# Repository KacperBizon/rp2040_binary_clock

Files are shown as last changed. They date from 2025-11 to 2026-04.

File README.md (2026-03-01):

# rp2040 binary clock
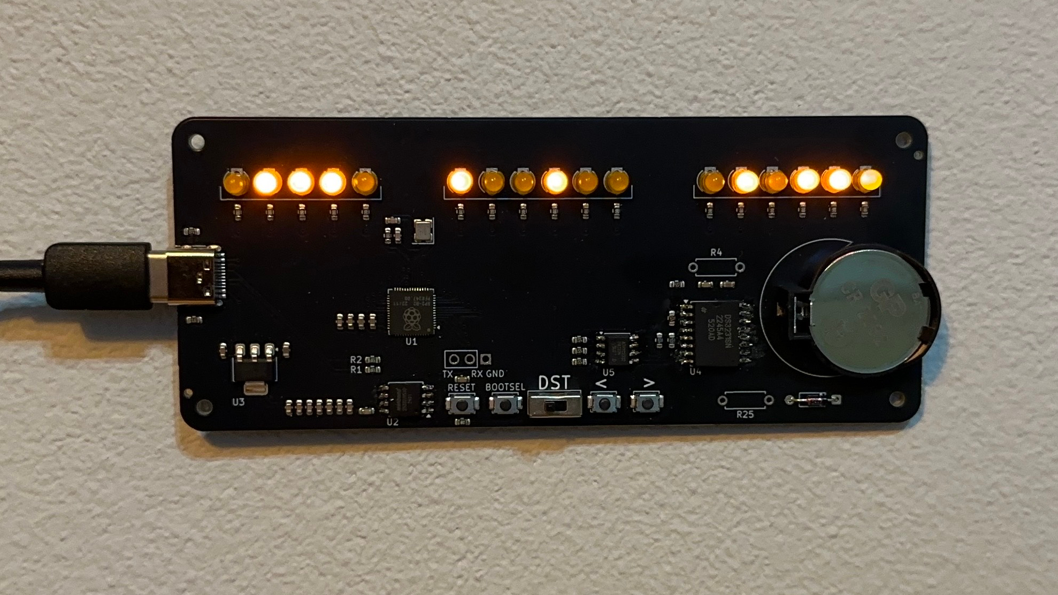
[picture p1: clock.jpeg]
clock image


## Flashing
1. Hold BOOTSEL button while plugging the USB
2. mount the device (RPI-RP2)
3. Drag the rp2040_binary_clock.uf2 to RPI-RP2

## Building from Source (Pico C/C++ SDK)
### Prerequisites
- Install CMake and Make
- Install arm-none-eabi-gcc
- Clone the [Raspberry Pi Pico SDK](https://github.com/raspberrypi/pico-sdk), ensure the submodules are initialized and set PICO_SDK_PATH.

### Compilation
```bash
git clone https://github.com/KacperBizon/rp2040_binary_clock.git
cd rp2040_binary_clock/firmware
mkdir build
cd build
cmake ..
make
```

## Optional resistors
- R4 - 10K - use only when having problems with writing to memory
- R25 - 1K - use only with lithium rechargeable batteries

## License & Acknowledgments
This project is distributed under the [MIT License](LICENSE).

Third-Party Components:
The `firmware/pico_sdk_import.cmake` file included in this repository is the intellectual property of Raspberry Pi (Trading) Ltd. and is distributed under the BSD 3-Clause License.

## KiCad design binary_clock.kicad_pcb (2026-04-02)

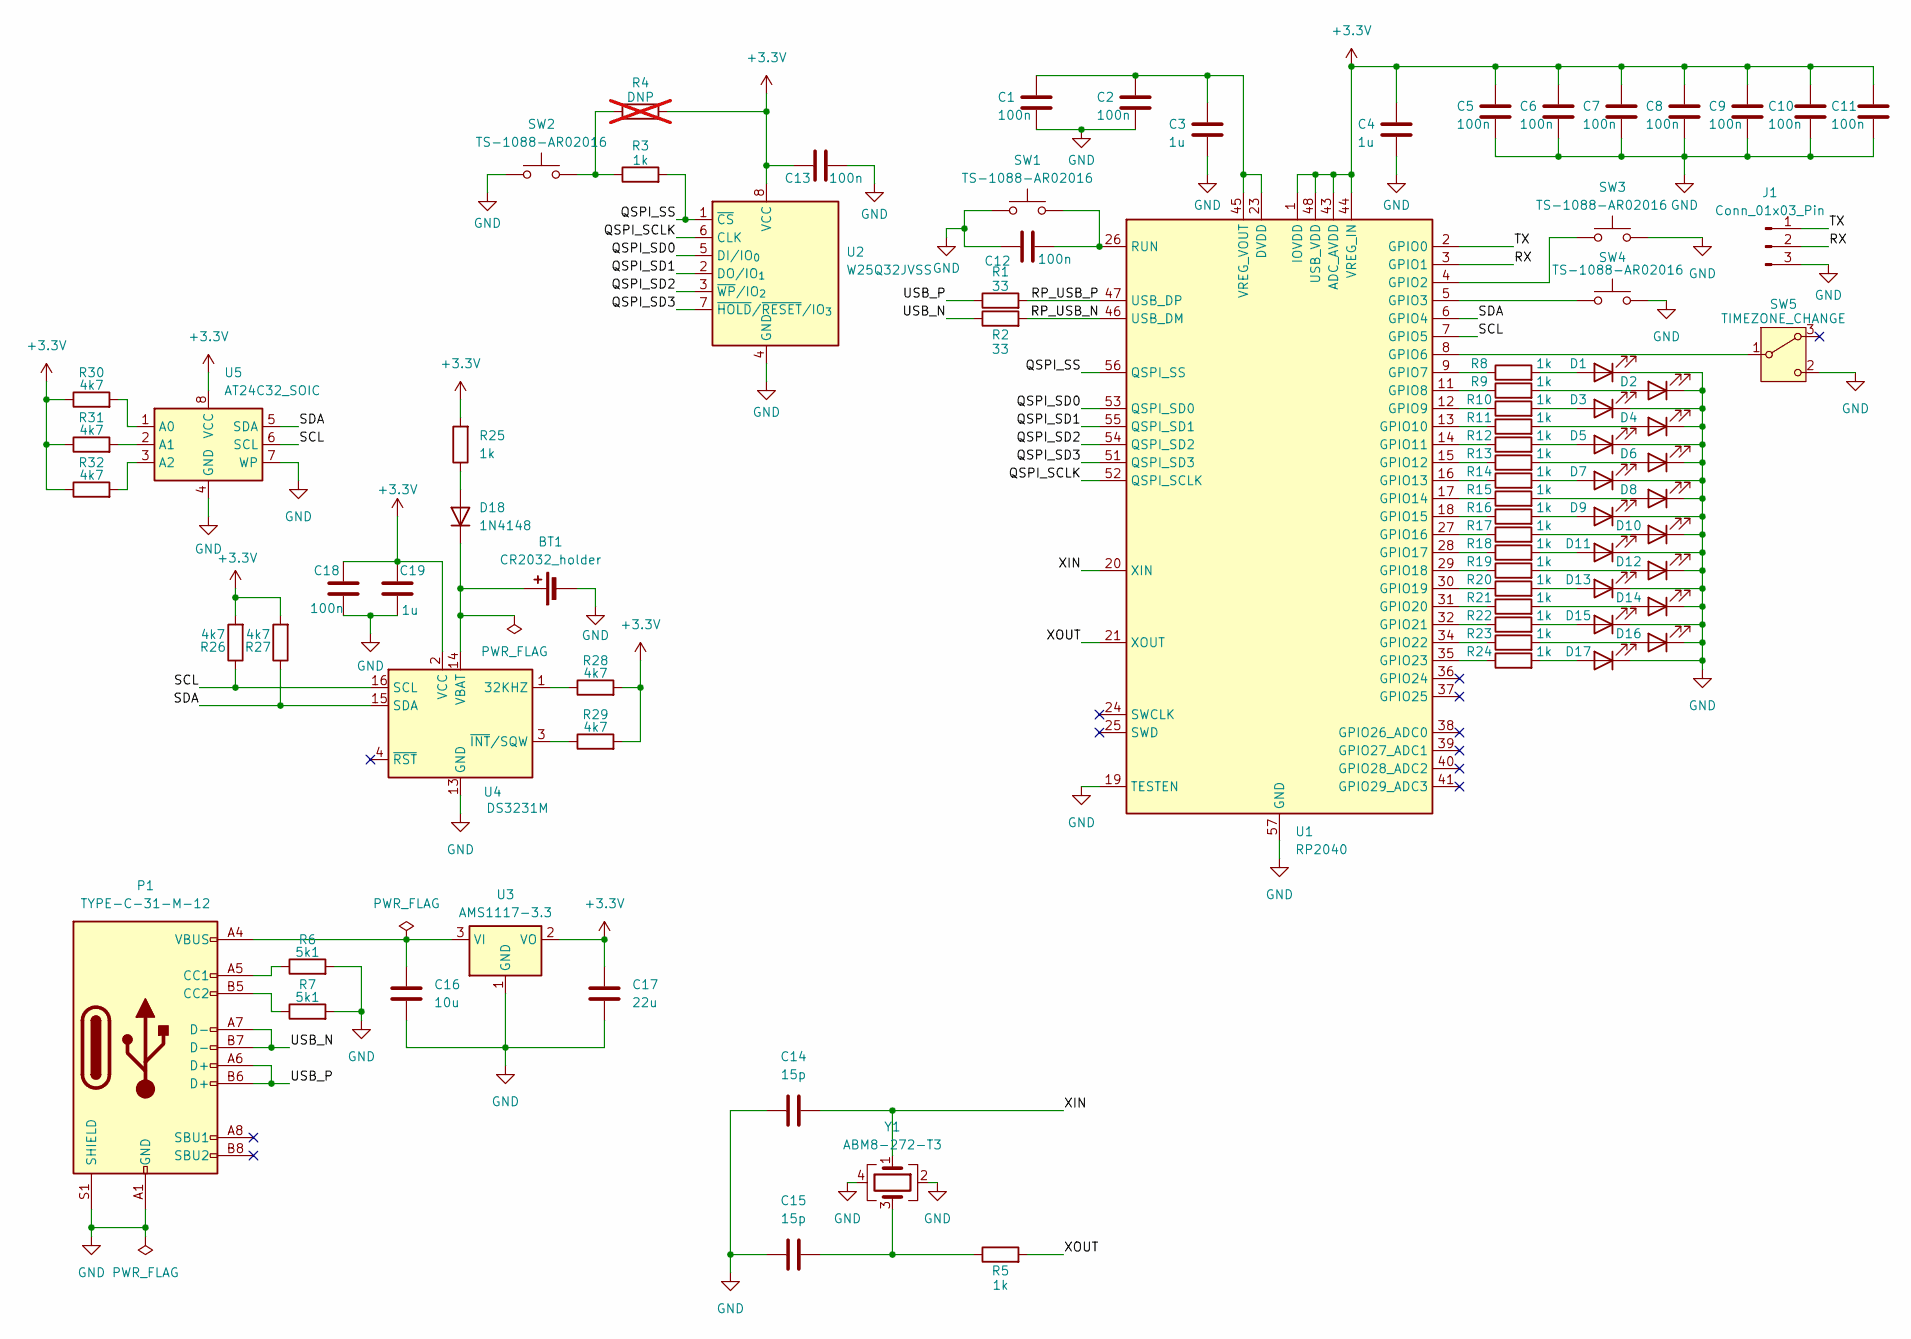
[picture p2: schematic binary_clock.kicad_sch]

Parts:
BT1: CR2032_holder; Battery_Holder_Coin_2032_BS-7
C1, C2, C5, C6, C7, C8, C9, C10, C11, C12, C13, C18: 100n; C_0603_1608Metric
C3, C4, C19: 1u; C_0603_1608Metric
C14, C15: 15p; C_0603_1608Metric
C16: 10u; C_0603_1608Metric
C17: 22u; C_0603_1608Metric
D1, D2, D3, D4, D5, D6, D7, D8, D9, D10, D11, D12, D13, D14, D15, D16, D17: LED; LED_D3.0mm
D18: 1N4148; D_DO-35_SOD27_P7.62mm_Horizontal
J1: Conn_01x03_Pin; PinHeader_1x03_P2.54mm_Vertical
P1: TYPE-C-31-M-12; USB_C_Receptacle_HRO_TYPE-C-31-M-12
R1, R2: 33; R_0603_1608Metric
R3, R5, R8, R9, R10, R11, R12, R13, R14, R15, R16, R17, R18, R19, R20, R21, R22, R23, R24: 1k; R_0603_1608Metric
R4: DNP; R_Axial_DIN0207_L6.3mm_D2.5mm_P7.62mm_Horizontal; not fitted
R6, R7: 5k1; R_0603_1608Metric
R25: 1k; R_Axial_DIN0207_L6.3mm_D2.5mm_P7.62mm_Horizontal
R26, R27, R28, R29, R30, R31, R32: 4k7; R_0603_1608Metric
SW1, SW2, SW3, SW4: TS-1088-AR02016; SW_SPST_TS-1088-xR020
SW5: TIMEZONE_CHANGE; SW_Slide_8.6x3.8x7.0_P2.54mm
U1: RP2040; QFN-56-1EP_7x7mm_P0.4mm_EP3.2x3.2mm
U2: W25Q32JVSS; SOIC-8_5.3x5.3mm_P1.27mm
U3: AMS1117-3.3; SOT-223-3_TabPin2
U4: DS3231M; SOIC-16W_7.5x10.3mm_P1.27mm
U5: AT24C32_SOIC; SOIC-8_3.9x4.9mm_P1.27mm
Y1: ABM8-272-T3; Crystal_SMD_Abracon_ABM8G-4Pin_3.2x2.5mm

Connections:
+3.3V: C4.2, C5.2, C6.2, C7.2, C8.2, C9.2, C10.2, C11.2, C13.2, C17.2, C18.2, C19.1, R4.2, R25.2, R26.2, R27.2, R28.2, R29.2, R30.1, R31.1, R32.1, U1.1 (IOVDD), U1.10 (IOVDD), U1.22 (IOVDD), U1.33 (IOVDD), U1.42 (IOVDD), U1.43 (ADC_AVDD), U1.44 (VREG_IN), U1.48 (USB_VDD), U1.49 (IOVDD), U2.8 (VCC), U3.2 (VO), U4.2 (VCC), U5.8 (VCC)
/QSPI_SCLK: U1.52 (QSPI_SCLK), U2.6 (CLK)
/QSPI_SD0: U1.53 (QSPI_SD0), U2.5 (DI/IO_{0})
/QSPI_SD1: U1.55 (QSPI_SD1), U2.2 (DO/IO_{1})
/QSPI_SD2: U1.54 (QSPI_SD2), U2.3 (~WP/IO_{2})
/QSPI_SD3: U1.51 (QSPI_SD3), U2.7 (~HOLD/~RESET/IO_{3})
/QSPI_SS: R3.2, U1.56 (QSPI_SS), U2.1 (~CS)
/RP_USB_N: R2.2, U1.46 (USB_DM)
/RP_USB_P: R1.2, U1.47 (USB_DP)
/RX: J1.2, U1.3 (GPIO1)
/SCL: R26.1, U1.7 (GPIO5), U4.16 (SCL), U5.6 (SCL)
/SDA: R27.1, U1.6 (GPIO4), U4.15 (SDA), U5.5 (SDA)
/TX: J1.1, U1.2 (GPIO0)
/USB_N: P1.A7 (D-), P1.B7 (D-), R2.1
/USB_P: P1.A6 (D+), P1.B6 (D+), R1.1
/XIN: C14.1, U1.20 (XIN), Y1.1
/XOUT: R5.2, U1.21 (XOUT)
GND: BT1.2 (-), C1.1, C2.1, C3.1, C4.1, C5.1, C6.1, C7.1, C8.1, C9.1, C10.1, C11.1, C12.2, C13.1, C14.2, C15.2, C16.1, C17.1, C18.1, C19.2, D1.1 (K), D2.1 (K), D3.1 (K), D4.1 (K), D5.1 (K), D6.1 (K), D7.1 (K), D8.1 (K), D9.1 (K), D10.1 (K), D11.1 (K), D12.1 (K), D13.1 (K), D14.1 (K), D15.1 (K), D16.1 (K), D17.1 (K), J1.3, P1.A1 (GND), P1.A12 (GND), P1.B1 (GND), P1.B12 (GND), P1.S1 (SHIELD), R6.2, R7.2, SW1.1, SW2.1, SW3.2, SW4.2, SW5.2 (C), U1.19 (TESTEN), U1.57 (GND), U2.4 (GND), U3.1 (GND), U4.5 (GND), U4.6 (GND), U4.7 (GND), U4.8 (GND), U4.9 (GND), U4.10 (GND), U4.11 (GND), U4.12 (GND), U4.13 (GND), U5.4 (GND), U5.7 (WP), Y1.2, Y1.4
unnamed: BT1.1 (+), D18.1 (K), U4.14 (VBAT)
unnamed: C15.1, R5.1, Y1.3
unnamed: D1.2 (A), R8.2
unnamed: D2.2 (A), R9.2
unnamed: D3.2 (A), R10.2
unnamed: D4.2 (A), R11.2
unnamed: D5.2 (A), R12.2
unnamed: D6.2 (A), R13.2
unnamed: D7.2 (A), R14.2
unnamed: D8.2 (A), R15.2
unnamed: D9.2 (A), R16.2
unnamed: D10.2 (A), R17.2
unnamed: D11.2 (A), R18.2
unnamed: D12.2 (A), R19.2
unnamed: D13.2 (A), R20.2
unnamed: D14.2 (A), R21.2
unnamed: D15.2 (A), R22.2
unnamed: D16.2 (A), R23.2
unnamed: D17.2 (A), R24.2
unnamed: D18.2 (A), R25.1
unnamed: P1.A5 (CC1), R6.1
unnamed: P1.B5 (CC2), R7.1
unnamed: R3.1, R4.1, SW2.2
unnamed: SW5.1 (B), U1.8 (GPIO6)
unnamed: SW3.1, U1.4 (GPIO2)
unnamed: SW4.1, U1.5 (GPIO3)
unnamed: R8.1, U1.9 (GPIO7)
unnamed: R9.1, U1.11 (GPIO8)
unnamed: R10.1, U1.12 (GPIO9)
unnamed: R11.1, U1.13 (GPIO10)
unnamed: R12.1, U1.14 (GPIO11)
unnamed: R13.1, U1.15 (GPIO12)
unnamed: R14.1, U1.16 (GPIO13)
unnamed: R15.1, U1.17 (GPIO14)
unnamed: R16.1, U1.18 (GPIO15)
unnamed: R17.1, U1.27 (GPIO16)
unnamed: R18.1, U1.28 (GPIO17)
unnamed: R19.1, U1.29 (GPIO18)
unnamed: R20.1, U1.30 (GPIO19)
unnamed: R21.1, U1.31 (GPIO20)
unnamed: R22.1, U1.32 (GPIO21)
unnamed: R23.1, U1.34 (GPIO22)
unnamed: R24.1, U1.35 (GPIO23)
unnamed: C12.1, SW1.2, U1.26 (RUN)
unnamed: C1.2, C2.2, C3.2, U1.23 (DVDD), U1.45 (VREG_VOUT), U1.50 (DVDD)
unnamed: C16.2, P1.A4 (VBUS), P1.A9 (VBUS), P1.B4 (VBUS), P1.B9 (VBUS), U3.3 (VI)
unnamed: R28.1, U4.1 (32KHZ)
unnamed: R29.1, U4.3 (~INT/SQW)
unnamed: R30.2, U5.1 (A0)
unnamed: R31.2, U5.2 (A1)
unnamed: R32.2, U5.3 (A2)

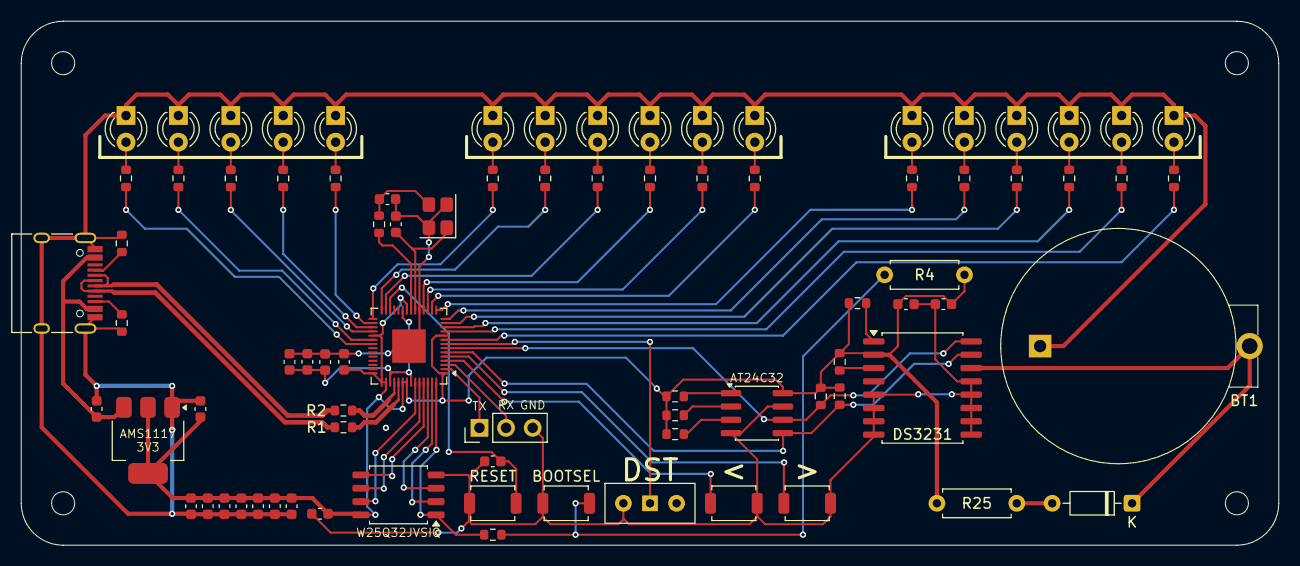
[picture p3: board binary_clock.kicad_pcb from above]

Board: 2 copper layers, 120.0 x 50.0 mm, 87 parts (0 on the bottom side), 69 nets.

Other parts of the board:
MH1, MH2, MH3, MH4: MountingHole_2.2mm_M2_DIN965

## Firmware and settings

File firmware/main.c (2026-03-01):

#include "hardware/i2c.h"
#include "hardware/watchdog.h"
#include "pico/stdlib.h"
#include <stdbool.h>
#include <stdint.h>
#include <stdio.h>
#include <string.h>
#include <time.h>

#define USE_GRAY_CODE 0

#define I2C_PORT i2c0
#define DS3231_ADDR 0x68
#define I2C_SDA_PIN 4
#define I2C_SCL_PIN 5

const uint8_t ledPinsSec[] = {7, 8, 9, 10, 11, 12};
const uint8_t ledPinsMin[] = {13, 14, 15, 16, 17, 18};
const uint8_t ledPinsHr[] = {19, 20, 21, 22, 23};

const uint8_t nBitsSec = sizeof(ledPinsSec) / sizeof(ledPinsSec[0]);
const uint8_t nBitsMin = sizeof(ledPinsMin) / sizeof(ledPinsMin[0]);
const uint8_t nBitsHr = sizeof(ledPinsHr) / sizeof(ledPinsHr[0]);

const uint8_t decrease_time_pin = 2;
const uint8_t increase_time_pin = 3;
const uint8_t time_zone_pin = 6;

bool dst = false;
uint8_t lastSecond = 0;

uint8_t seconds = 60;
uint8_t minutes = 0;
uint8_t hours = 0;

static inline uint8_t bcd_to_dec(uint8_t val)
{
  return ((val >> 4) * 10) + (val & 0x0F);
}

static inline uint8_t dec_to_bcd(uint8_t val)
{
  return ((val / 10) << 4) | (val % 10);
}

// I2C DS3231 Operations
void rtc_get_time(struct tm *t)
{
  uint8_t reg = 0x00;
  uint8_t buf[7];
  i2c_write_blocking(I2C_PORT, DS3231_ADDR, &reg, 1, true);
  i2c_read_blocking(I2C_PORT, DS3231_ADDR, buf, 7, false);

  t->tm_sec = bcd_to_dec(buf[0] & 0x7F);
  t->tm_min = bcd_to_dec(buf[1]);
  t->tm_hour = bcd_to_dec(buf[2] & 0x3F);
  t->tm_mday = bcd_to_dec(buf[4]);
  t->tm_mon = bcd_to_dec(buf[5] & 0x1F) - 1;
  t->tm_year = bcd_to_dec(buf[6]) + 100;
}

void rtc_set_time(struct tm *t)
{
  uint8_t buf[8];
  buf[0] = 0x00;
  buf[1] = dec_to_bcd(t->tm_sec);
  buf[2] = dec_to_bcd(t->tm_min);
  buf[3] = dec_to_bcd(t->tm_hour);
  buf[4] = 1; // Arbitrary day of week
  buf[5] = dec_to_bcd(t->tm_mday);
  buf[6] = dec_to_bcd(t->tm_mon + 1);
  buf[7] = dec_to_bcd(t->tm_year - 100);

  i2c_write_blocking(I2C_PORT, DS3231_ADDR, buf, 8, false);
}

bool rtc_lost_power()
{
  uint8_t reg = 0x0F;
  uint8_t status;
  i2c_write_blocking(I2C_PORT, DS3231_ADDR, &reg, 1, true);
  i2c_read_blocking(I2C_PORT, DS3231_ADDR, &status, 1, false);
  return (status & 0x80) != 0; // Evaluate OSF
}

void rtc_clear_osf()
{
  uint8_t reg = 0x0F;
  uint8_t status;
  i2c_write_blocking(I2C_PORT, DS3231_ADDR, &reg, 1, true);
  i2c_read_blocking(I2C_PORT, DS3231_ADDR, &status, 1, false);
  status &= ~0x80;
  uint8_t buf[2] = {0x0F, status};
  i2c_write_blocking(I2C_PORT, DS3231_ADDR, buf, 2, false);
}

void rtc_adjust_to_compile_time()
{
  const char *month_names[] = {"Jan", "Feb", "Mar", "Apr", "May", "Jun",
                               "Jul", "Aug", "Sep", "Oct", "Nov", "Dec"};
  char s_month[5];
  int day, year, hour, min, sec;

  sscanf(__DATE__, "%s %d %d", s_month, &day, &year);
  sscanf(__TIME__, "%d:%d:%d", &hour, &min, &sec);

  struct tm t = {0};
  for (int i = 0; i < 12; i++)
  {
    if (strncmp(s_month, month_names[i], 3) == 0)
    {
      t.tm_mon = i;
      break;
    }
  }
  t.tm_mday = day;
  t.tm_year = year - 1900;
  t.tm_hour = hour;
  t.tm_min = min;
  t.tm_sec = sec;

  rtc_set_time(&t);
  rtc_clear_osf();
}

bool rtc_ping()
{
  uint8_t dummy = 0;
  int ret = i2c_read_blocking(I2C_PORT, DS3231_ADDR, &dummy, 1, false);
  return ret != PICO_ERROR_GENERIC;
}

// Display Logic
#if USE_GRAY_CODE
uint8_t toGray(uint8_t value) { return value ^ (value >> 1); }
#endif

void dispBinary(uint8_t value, const uint8_t *pins, uint8_t nBits)
{
#if USE_GRAY_CODE
  value = toGray(value);
#endif

  for (uint8_t i = 0; i < nBits; i++)
  {
    gpio_put(pins[i], value & 1);
    value >>= 1;
  }
}

// Initialization
void setup(void)
{
  gpio_init(decrease_time_pin);
  gpio_set_dir(decrease_time_pin, GPIO_IN);
  gpio_pull_up(decrease_time_pin);

  gpio_init(increase_time_pin);
  gpio_set_dir(increase_time_pin, GPIO_IN);
  gpio_pull_up(increase_time_pin);

  gpio_init(time_zone_pin);
  gpio_set_dir(time_zone_pin, GPIO_IN);
  gpio_pull_up(time_zone_pin);

  for (uint8_t i = 0; i < nBitsSec; i++)
  {
    gpio_init(ledPinsSec[i]);
    gpio_set_dir(ledPinsSec[i], GPIO_OUT);
  }
  for (uint8_t i = 0; i < nBitsMin; i++)
  {
    gpio_init(ledPinsMin[i]);
    gpio_set_dir(ledPinsMin[i], GPIO_OUT);
  }
  for (uint8_t i = 0; i < nBitsHr; i++)
  {
    gpio_init(ledPinsHr[i]);
    gpio_set_dir(ledPinsHr[i], GPIO_OUT);
  }

  i2c_init(I2C_PORT, 400 * 1000);
  gpio_set_function(I2C_SDA_PIN, GPIO_FUNC_I2C);
  gpio_set_function(I2C_SCL_PIN, GPIO_FUNC_I2C);
  gpio_pull_up(I2C_SDA_PIN);
  gpio_pull_up(I2C_SCL_PIN);

  i2c_deinit(I2C_PORT);
  sleep_ms(30);
  i2c_init(I2C_PORT, 400 * 1000);
  sleep_ms(30);

  while (!rtc_ping())
  {
    gpio_put(ledPinsHr[nBitsHr - 1], !gpio_get(ledPinsHr[nBitsHr - 1]));
    i2c_init(I2C_PORT, 400 * 1000);
    sleep_ms(500);
  }

  if (rtc_lost_power())
  {
    rtc_adjust_to_compile_time();
  }

  watchdog_enable(5000, 1);
}

// Update Functions
void checkButtons()
{
  static uint32_t last_button_action = 0;
  uint32_t current_ms = to_ms_since_boot(get_absolute_time());

  dst = gpio_get(time_zone_pin);

  if (current_ms - last_button_action > 220)
  {
    bool decrease_active = !gpio_get(decrease_time_pin);
    bool increase_active = !gpio_get(increase_time_pin);

    if (decrease_active || increase_active)
    {
      last_button_action = current_ms;

      struct tm now;
      rtc_get_time(&now);

      if (decrease_active)
      {
        now.tm_min -= 1;
      }
      else
      {
        now.tm_min += 1;
      }

      now.tm_sec = 0;
      mktime(&now);

      rtc_set_time(&now);
      lastSecond = 60;
    }
  }
}

void updateClock()
{
  static uint32_t lastReadTime = 0;
  uint32_t current_ms = to_ms_since_boot(get_absolute_time());

  if (current_ms - lastReadTime > 100)
  {
    lastReadTime = current_ms;

    struct tm now;
    rtc_get_time(&now);

    if (now.tm_sec != lastSecond)
    {
      lastSecond = now.tm_sec;

      seconds = now.tm_sec;
      minutes = now.tm_min;
      hours = now.tm_hour;

      if (dst)
      {
        hours = (hours + 1) % 24;
      }

      dispBinary(seconds, ledPinsSec, nBitsSec);
      dispBinary(minutes, ledPinsMin, nBitsMin);
      dispBinary(hours, ledPinsHr, nBitsHr);
    }
  }
}

int main()
{
  stdio_init_all();
  setup();

  while (true)
  {
    watchdog_update();
    checkButtons();
    updateClock();
  }

  return 0;
}

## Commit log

2025-10-31 rp2040 schematic done, wrong usb c
    [binary_clock.kicad_pcb, binary_clock.kicad_sch]
2025-11-01 added switches and labels for i2c0
    [binary_clock.kicad_pcb, binary_clock.kicad_sch]
2025-11-01 added rtc clock and diodes
    [binary_clock.kicad_sch]
2025-11-01 half pcb done and cutouts
    [binary_clock.kicad_pcb]
2025-11-02 pcb finished
    [binary_clock.kicad_pcb]
2025-11-02 final pcb, ignore production/
    [binary_clock.kicad_pcb, binary_clock.kicad_sch]
2025-11-14 cr2032 holder footprint fix, gitignore build
    [binary_clock.kicad_pcb]
2025-11-15 added button function
2025-12-20 Widen power tracks and improve solderability
    [binary_clock.kicad_pcb]
2026-02-16 change silkscreen, adjust footprints
    [binary_clock.kicad_pcb]
2026-04-02 add USB netclass
    [binary_clock.kicad_sch]
2026-04-02 update USB differential pair geometry for 90 ohm coplanar impedance
    [binary_clock.kicad_pcb]
